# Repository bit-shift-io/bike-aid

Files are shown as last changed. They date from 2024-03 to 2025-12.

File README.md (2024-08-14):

# bike-aid

This is an ebike govenor which does the following:

* Bluetooth interface
* Power toggle
* Lights toggle
* Horn toggle
* Battery power, voltage, current meter
* Alarm system
* Speedometer
* Odometer
* Trip duration
* Throttle smoothing
* Throttle limiting / speed limiting
* Throttle deadband adjustment

## Purpose

I designed this tool as a controller to act as a interface for controlling my ebike. I have had a few ebikes now, and they are all missing basic features I wanted.

## Where to start

* mcu-nrf-rs - mcu software
* app-java - android app  
* docs - documentation
* diagrams - circuit diagrams
* everything else is old!

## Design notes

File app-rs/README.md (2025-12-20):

# Bike Aid (Rust + Flutter)

A high-performance, multiplatform Bluetooth application built with **Flutter** for the UI and **Rust** for the core logic.

> **Architecture Note**: This project uses **Rust** for all core application logic (UUIDs, parsing, state management) and **Dart/Flutter** strictly for the GUI and device transport. This separation allows for easily swapping the GUI framework in the future while preserving the business logic.

## Project Structure

### 🛠️ Core Logic (Rust)
The "brain" of the app lives in the `rust/` directory.
- **protocol.rs**: **Entry Point.** Contains the scooter protocol implementation.
  - `ScooterState`: The central data structure representing the bike (speed, battery, light status, etc.).
  - `parse_characteristic_data()`: Converts raw bytes from the bike into the `ScooterState`.
  - `create_command_bytes()`: Generates the raw bytes to send to the bike for actions like Power, Alarm, or Horn.
- **`src/api/`**: Contains the modules exposed to Flutter.

### 📱 Frontend (Flutter)
The UI and Bluetooth transport are in the `lib/` directory.
- **main.dart**: **GUI Entry Point.**
  - **Bluetooth Manager**: Handles scanning for "BScooter", auto-connecting, and characteristic subscriptions.
  - **Page Navigation**: Implements the fullscreen `PageView` (Dashboard <-> Log).
  - **Control Panel**: The button-based interface that triggers Rust commands.
- **`lib/src/rust/`**: **Generated Bridge.** Contains the Dart bindings that allow calling Rust functions seamlessly.

## Prerequisites

- **Flutter SDK**
- **Rust** (Stable)
- **Android NDK** (for Android builds)

## Setup & Running

### 1. Fix PATH & Install Tools (Once)
```fish
set -U fish_user_paths $HOME/.cargo/bin $fish_user_paths
cargo install flutter_rust_bridge_codegen --version 2.11.1
rustup target add aarch64-linux-android armv7-linux-androideabi x86_64-linux-android i686-linux-android
```

### 2. Generate Code
Run this to link the Rust code and generate translations:
```bash
flutter_rust_bridge_codegen generate
dart run slang
```

### 3. Run the App
```bash
flutter run
```

## Features
- **Native Bluetooth**: Fast and reliable scanning using `flutter_blue_plus`.
- **HTTP Entry Control**: Control IoT entry points via HTTP requests (with offline queuing).
- **Log & Diagnostic Terminal**: Real-time logging of Bluetooth commands and responses with manual UART input.
- **Permission Handling**: Dynamic requests for Location and Bluetooth.
- **Dark Theme**: Modern Material 3 dark UI.

## Troubleshooting

- **Missing Imports**: If `main.dart` shows errors after generation, uncomment the bridge imports at the top of the file.
- **Cargo Expand**: If generation fails with "cargo expand returned empty output", run `cargo build` inside the `rust/` folder once.

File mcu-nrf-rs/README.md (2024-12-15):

# Installation Guide

## Wiring
```
Raspberry pi debug probe (port D)   ->  NRF
TX/SC (orange - out from probe)     ->  CLK (orange - SWC) 
GND (black)                         ->  GND (black)
RX/SD (yellow - input to I/O)       ->  DIO (yellow - SWD)
```

## Tools
```Bash
# Probe-RS
curl --proto '=https' --tlsv1.2 -LsSf https://github.com/probe-rs/probe-rs/releases/latest/download/probe-rs-tools-installer.sh | sh

# USB Permissions
sudo usermod -aG uucp $USER # not sure if we need this one?

# need the udev rule
sudo cp 69-probe-rs.rules /etc/udev/rules.d/
sudo udevadm control --reload
sudo udevadm trigger

# Debugger - not required
#sudo pacman -S gdb-common openocd

# list debug probe
probe-rs list
```

## Getting rust working
Run ```cargo build``` in the rust project root directory  
Then ```cargo run```  
or ```cargo embed``` for user input terminal

## Error: No connected probes were found.
Need to configure udev rules in linux
```bash
probe-rs list
ls /dev/ttyACM*
lsusb
```

## Erase the chip
```bash
probe-rs erase --chip nRF52840_xxAA
```

## Get latest rust toolchain
```bash
rustup update
```

## Update nrf42840 firmware for bluetooth
Downloaded from 
```
https://www.nordicsemi.com/Products/Development-software/s140/download
```

Flash using the commands:
```bash
probe-rs erase --chip nrf52840_xxAA --allow-erase-all
probe-rs download --verify --binary-format hex --chip nRF52840_xxAA s140_nrf52_7.3.0_softdevice.hex
```

## Debug support
Install probe-rs visual studio plugin  
Download the svd ```https://github.com/nrf-rs/nrf-pacs/tree/master/svds```  
Old - Download the svd ```https://github.com/NordicSemiconductor/nrfx/blob/master/mdk/nrf52840.svd```  

## Reset device
Double tap rest to ground within 0.5 seconds to reset board

## Stuck in boot loop (bad flash)
Reflash the firmware above

## Pin Guide
* P0.31 - LED
* P0.29 - Piezo
* P0.20 - Manual Override
* P0.17 - Brake
* P0.09 - Speed
* P0.10 - Power Switch
* P0.10 - Light
* P1.11 - Horn
* P0.06 - I2C SCL - Orange ( Green on breadboard )
* P0.08 - I2C SDA - Yellow

## Pin Notes
* nfc-pins-as-gpio Allow using the NFC pins as regular GPIO P0_09/P0_10 on nRF52
* reset-pin-as-gpio Allow using the RST pin as a regular GPIO P0_18

* P0.13 controls vcc output on/off 3.3v
* P0.14-0.16 set low resets ?
* p0.15 Debug LED

## Hardware Todo
* try a smaller pulldown on the throttle module, replace 100k with 47k to see if it helps with floating throttle
* brake plug seems wobbly
* reset push button - hw
* speedo - hardware/oscilliscope
* brake supply 5v with diode to drop 0.7v. then can setup parkbrake to turn off power.

## App Todo
* disconnect while connecting causes multiple instances of scanner

## MCU Todo
* patch qeue predicate filter
* attach debugger to running mcu
* sport mode acceleration values 10% higher?
* alarm
* ble tracker
* odometer/speed

## Links

https://github.com/peterkrull/quad/blob/main/software/rusty-quad/src/

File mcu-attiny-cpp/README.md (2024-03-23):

# bike-aid
ebike throttle aid using arduino

### Purpose

Arduino Throttle Correction for 3-wire thottles

This project is suitable for electric vehicles with a non-programmable controller. 
The arduino is inserted between a 3-wire throttle and the controller.

* Provides smoothing for aggressive throttle response by slowing down changes in output (wheelie/jerk control)
* Reduces throttle dead-band/deadzone by mapping input to output values as per configuration
* Optionally provides an adjustable speed limit (hardcoded or potentiometer/switch)

### Wiring and Implementation

Wiring is very simple.  Smoothing capacitor can be any value that eliminates
jumping of motor speed at steady throttle.  I used a 10uF for my setup.  
A high value may cause the throttle to stay high longer than desired. 

### Tuning

Tune behaviors according to your throttle's actual values, which you can see if you watch serial output.

If you don't want speed limiting, comment out `#LIMIT_ENABLE`

**Note** that when plugged into USB, Arduino is running at 5V, but when powered by the motor controller,
it is most likely running on 4.0V-4.5V.  This changes the numbers and behavior a little when you unplug USB.

### Programming attiny85
https://www.instructables.com/How-to-Program-an-Attiny85-From-an-Arduino-Uno/
Files > Preferences > Additional Board Managers ...
https://raw.githubusercontent.com/damellis/attiny/ide-1.6.x-boards-manager/package_damellis_attiny_index.json
Restart the IDE
Tools > Boards > Board Manager
Install 'attiny'
Restart IDE
Tools > Boards > attiny

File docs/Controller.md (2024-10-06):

# EBike Controller

## Notes
Power switch take 48v, 16mA @ 55v

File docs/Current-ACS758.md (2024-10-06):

# ACS758LCB-050B Current Sensor
ACS758LCB-050B Range Linear Current Sensor Analog Signal Output for Arduino Hall Effect Based
Features and Benefits

## Notes

Maximum current: 100A
Voltage：3.3-5V
temperature：-41°C ~ 152°C
Industry-leading noise performance through proprietary amplifier and filter design techniques
Integrated shield greatly reduces capacitive coupling from current conductor to die due to high dV/dt signals, and prevents offset drift in high-side, high voltage applications
Total output error improvement through gain and offset trim over temperature
Small package size, with easy mounting capability
Monolithic Hall IC for high reliability
Ultra-low power loss: 100 μΩ internal conductor resistance
Galvanic isolation allows use in economical, high-side current sensing in high voltage systems
3.0 to 5.5 V, single supply operation
120 kHz typical bandwidth
3 μs output rise time in response to step input current
Output voltage proportional to AC or DC currents
Factory-trimmed for accuracy
Extremely stable output offset voltage
Nearly zero magnetic hysteresis

## Information

https://www.youtube.com/watch?v=SiHfjzcqnU4
http://robojax.com/learn/arduino/?vid=robojax-allegro_ACS758 - tutorial + source
http://robojax.com/download/datasheet/robojax_ACS758_current_sensor_datasheet.pdf

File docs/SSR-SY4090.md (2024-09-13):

# Solid State Relay SY4090

https://www.jaycar.co.nz/pcb-mount-solid-state-dil-relay/p/SY4090

## Notes

https://forum.arduino.cc/t/switch-55-60v-16ma-advice-optocouplers/1300792/10

## Calculations

V=IR
R=V/I
Forward Voltage LED = 1.2-1.3v
3.3v - 1.3v = 2v - 2.1v
R=2v/0.006A = 330ohm

## Pins
1 = +3.3v
2 = GND
3 = N/C
4/6 = Drain - Battery Input +60v 
5 = Source - Switched Output

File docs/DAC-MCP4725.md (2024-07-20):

# MCP4725 DAC

## Notes

MCP4725 Breakout Board 12-bit DAC I2C Interface
Use MCP4725 chip
12 DAC
Standard I2C interface
Power supply voltage 2.7-5.5V

## Information

https://www.aliexpress.com/item/1005005333707982.html?spm=a2g0o.order_list.order_list_main.90.66251802PaTEXk

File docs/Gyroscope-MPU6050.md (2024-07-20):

# MPU-6050 Gyroscope, Accelerometer, Temperature

## Information

https://randomnerdtutorials.com/arduino-mpu-6050-accelerometer-gyroscope/

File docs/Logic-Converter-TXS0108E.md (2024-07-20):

# TXS0108E Logic Converter

## Notes

Module uses the chip: TXS0108E
8-way high-speed full-duplex level conversion module
Provide two-way communication capability
VCCA terminal voltage of 1.2V-3.6V support
VCCB side support voltage 1.65v-5.5v
You can provide other common 3.3-5V 1.8-3.3v level conversion capability
The main application, 5V and 3.3V microcontroller module with 5V 3.3V microcontroller module, compatible with other communications support
MCU and SD card communication level conversion
SCM and iic, spi serial device level converter
OE active high enable IO recommended by a low voltage side of the IO port

## Information

https://www.aliexpress.com/item/1005006191464937.html?spm=a2g0o.order_list.order_list_main.56.66251802PaTEXk

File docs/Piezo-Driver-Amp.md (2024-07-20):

# Piezo Driver Amplifier

## Notes

Piezos make noise when you put an AC voltage across them: and the bigger the Vpp the louder they are. With your standard 3V logic microcontroller you can make 3Vpp with a PWM out, or 6Vpp differential with two complimentary outputs. But what if you want even louder? Or if you're using a piezo to sense distance using ultrasonic bounces?

We found the nifty PAM8904, which is an amplifier specifically designed for driving piezo elements - and unlike audio amplifiers it's good for up to 300 KHz! It's a switched-cap piezo driver that has bridge-tied load (BTL) output and up to 3x voltage multiplication thanks to a built in boosting circuit for up to ~13Vpp.

We whipped up a quick breakout in our 2mm JST-PH STEMMA form-factor to make it easy for anyone who wants to beep their boops very loudly. 

Usage is easy: power with 3 to 5VDC on the Vin and GND pins. Then provide a square wave on the signal pin, from 20Hz to 300KHz - any duty cycle is ok but 50% will probably work best. Theres a dual DIP switch to set the gain: you can set it to off (zero gain), x1 gain, x2 gain and x3 gain. The output is differential so 2x gain will give you 4xVin peak-to-peak across the piezo lines. Connect your piezo to the terminal block and you're ready to rock. 

Please note: If you are powering the driver from 5VDC, don't set the gain to x3 because the 15V output is higher than the driver is specified for. (Yeah we also sorta wondered why the chip manufacturer allows it). So if you are using 3.3V power, x3 gain is OK and will give you about 10V out but if you're powering with 5V use 2x gain max to keep the max voltage at 10V.

# Information

https://www.adafruit.com/product/5791
https://learn.adafruit.com/adafruit-stemma-piezo-driver-amp
https://learn.adafruit.com/adafruit-stemma-piezo-driver-amp/pinouts
https://dev.to/theembeddedrustacean/stm32f4-embedded-rust-at-the-hal-pwm-buzzer-3f1b

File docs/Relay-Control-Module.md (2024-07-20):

# Relay Control Module

## Notes

Specification:
Certification: NONE
Origin: Mainland China
Model Number: Relays Control Module
Main components: EL817, SRD-DC03V-SL-C
Voltage: DC 3V/3.3V
Can control 10A 250VAC, 10A 30VDC loads
Product weight: 20g
Product size: 70*20*17mm/2.76*0.79*0.67in
Note:
Due to the different monitor and light effect, the actual color of the item might be slightly different from the color showed on the pictures. Thank you!
Please allow 1-2cm measuring deviation due to manual measurement.
DC 3V/3.3V High Level Driver Module Output Signal Indicator High Level Trigger Microcontroller IO Port Optocoupler Relay Module
Features:
1. Output Signal Indicator: Equipped with an output signal indicator light, this dc 3v/3.3v high level driver module allows users to easily monitor and confirm the status of the signal output.
2. MCU-Compatible Input: With a signal input port that can be connected to MCU I/O pins, high level trigger provides a high-level signal drive and is compatible with various microcontrollers for easy integration into electronic projects.
3. Dual Power Supply Design: Featuring a dual power supply design, this product has strong anti-interference capabilities and reliable optical isolation protection, ensuring safe and stable signal transmission even in noisy environments.
4. Diode Continuity Protection: Equipped with diode continuity protection, optocoupler relay module can prevent any reverse current from dam aging the device and provide additional safety for your electronic projects.
5. Fast Response Time &amp; Long Relay Life: With a response time of less than 20 milliseconds and a relay life of up to 100,000 continuous operations, high level driver module delivers fast and reliable performance for various automation and control applications.
1 xIsolated Drive Control Board 

## Information

https://www.aliexpress.com/item/1005006178179016.html?spm=a2g0o.order_list.order_list_main.5.45b61802edvlUA

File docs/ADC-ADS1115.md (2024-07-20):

# ADC ADS1115

https://www.ti.com/product/ADS1115

## Notes

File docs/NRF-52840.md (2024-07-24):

# NRF 52840

https://wiki.icbbuy.com/doku.php?id=developmentboard:nrf52840

https://github.com/joric/nrfmicro/wiki/Alternatives#supermini-nrf52840

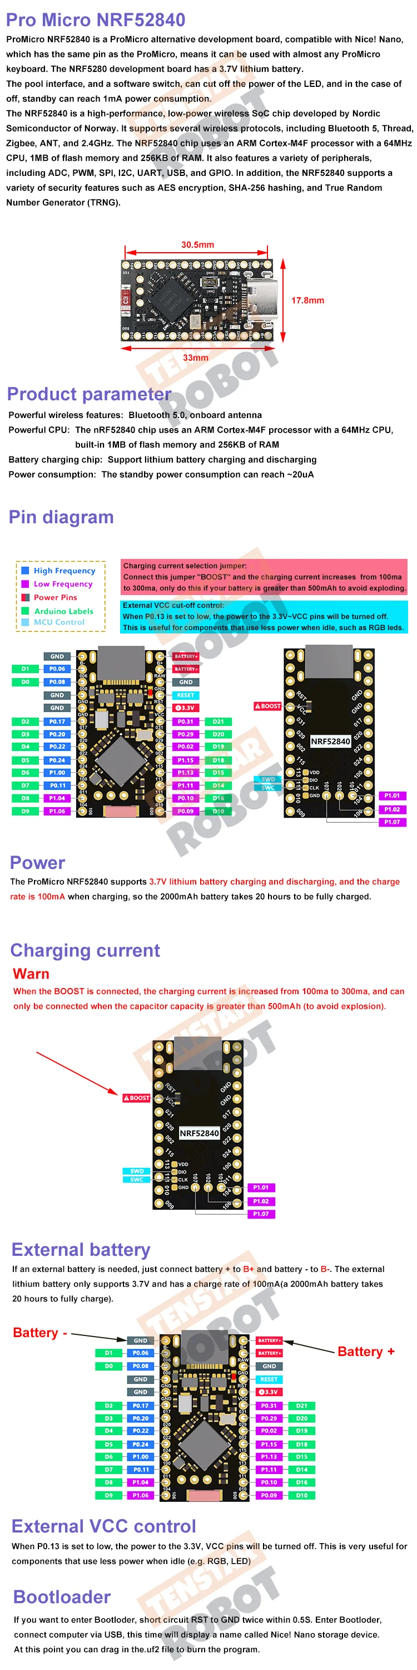
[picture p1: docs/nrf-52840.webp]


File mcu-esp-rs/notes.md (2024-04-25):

https://github.com/esp-rs/esp-hal/tree/main/examples
https://github.com/peterkrull/quad/blob/main/software/rusty-quad/src/task_blinker.rs
https://github.com/embassy-rs/embassy/blob/main/examples/nrf52840/src/bin/channel_sender_receiver.rs
https://github.com/apollolabsdev/ESP32C3/blob/main/embassy_examples/gpio/src/main.rs
https://dev.to/apollolabsbin/sharing-data-among-tasks-in-rust-embassy-synchronization-primitives-59hk
https://hegdenu.net/posts/understanding-async-await-3/

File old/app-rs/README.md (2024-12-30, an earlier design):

# Bike-Aid-App

A Rust application that's using [Slint](https://slint.rs) for the user interface. Using bluetooth low energy (BLE) and desktop and mobile app.

## VSCode plugins
Slint  
rust-analyzer  
CodeLLDB  

## Setup Android
Install sdk & ndk in the ~/Android/ directory  

Install dependencies  
```bash
sudo pacman -S jdk17-openjdk 
# clang lld llvm - use android ndk tools instead
```

Install android tools
```bash
sudo pacman -S android-tools android-udev
```

Set env variables in ~/.bash_profile 
```bash
export ANDROID_HOME=$HOME/Android/Sdk
export ANDROID_NDK_HOME=$ANDROID_HOME/ndk/28.0.12674087/
export ANDROID_NDK_ROOT=$ANDROID_NDK_HOME
export PATH=$PATH:$ANDROID_NDK_HOME/toolchains/llvm/prebuilt/linux-x86_64/bin

# for skia bindings
export ANDROID_NDK=$ANDROID_NDK_HOME
export CC_aarch64_linux_android=aarch64-linux-android26-clang
export CXX_aarch64_linux_android=aarch64-linux-android26-clang++
export AR_aarch64_linux_android=llvm-ar
export CARGO_TARGET_AARCH64_LINUX_ANDROID_LINKER=aarch64-linux-android26-clang
```

Install rust tools
```bash
rustup update
rustup target add aarch64-linux-android
cargo install cargo-ndk
```

Run and test
```sudo adb devices```

## Android Gradle Build
``` bash
cargo ndk -t arm64-v8a -o android/app/src/main/jniLibs/  build --features=android
cd android
./gradlew build
./gradlew installDebug
```

working as an apk... need libs?
```bash
cargo apk run --target aarch64-linux-android --lib
```

## Android xbuild -old?
```bash
x doctor
x devices
x build
x build --device adb:<id>
x run --device adb:<id>
```

## Android cargo-apk - untested
```bash
rustup target add aarch64-linux-android
cargo install cargo-apk
cargo apk build
cargo apk run
```

## Build external packages
```
<cd to Projects folder>
git clone https://github.com/deviceplug/jni-utils-rs.git
cd jni-utils-rs
cargo build --features=build-java-support
jar files located in /target/debug/java/libs

cd ..
git clone https://github.com/deviceplug/btleplug.git
cd btleplug/src/droidplug/java
edit build.gradle, comment and replace:
dependencies {
    implementation files('/home/bronson/Projects/jni-utils-rs/target/debug/java/libs/jni-utils-0.1.1-SNAPSHOT.jar')
}
./gradlew build 
btleplug/src/droidplug/java/build/outputs/aar/
```
an optional idea could be to merge the 2 android folders and build?

## Getting rust working
Run ```cargo build``` in the rust project root directory  
Then ```cargo run```

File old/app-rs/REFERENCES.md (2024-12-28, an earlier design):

## Links

#### BLE

https://github.com/MnlPhlp/blec

#### Android
https://github.com/slint-ui/slint/tree/3aafce2c52fa1e14971e4f2455bdc556daeb079d/internal/backends/android-activity

https://github.com/slint-ui/slint/blob/master/examples/todo/rust/lib.rs

https://git.sr.ht/~tmpod/eigen/tree/main/item/src

https://github.com/search?q=repo%3Aslint-ui%2Fslint%20android&type=code

https://crates.io/crates/android-activity

https://docs.rs/android-manifest/latest/android_manifest/struct.UsesPermission.html

#### JNI

https://docs.rs/jni/latest/jni/

https://github.com/astonbitecode/j4rs

#### Build.rs

https://github.com/slint-ui/slint/blob/e0f3fd4168fa6ad5ed17a50910111ed72d1ae95e/internal/backends/android-activity/build.rs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

# btleplug

https://github.com/deviceplug/btleplug/tree/master
https://github.com/deviceplug/btleplug/issues/8
https://gist.github.com/qdot/210f31439888927fc23b14d2e3d40503

# other apps

https://github.com/MiniMinerX/bevy_gaussian_oxr_simple/blob/main/manifest.yaml

https://gitlab.com/loikki/open-biking/-/tree/main?ref_type=heads
https://github.com/kyrosle/bevy_android
https://github.com/rust-mobile/xbuild
https://github.com/slint-ui/slint/blob/e125da180d34df9e221cb925ea5c1af6e813bd8f/api/rs/slint/android.rs
https://github.com/trobanga/flutter_btleplug/tree/frb2
https://github.com/intiface/intiface-central/tree/main
https://github.com/rib/bluey

# crate apis
https://github.com/rust-mobile/android-activity
https://github.com/rust-mobile/ndk

# idea

1. get access to the class loader from android-activity(slint is using this).
2. load the classes using this method.
see here: 

https://github.com/rust-mobile/android-activity/issues/82

https://github.com/rib/bluey/blob/5f351c50e6f396bc4fef9c050599f9668c63b339/bluey/src/android/session.rs#L1017

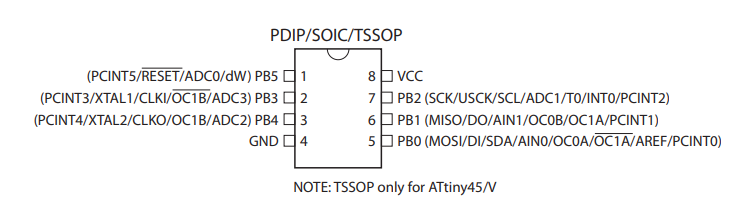
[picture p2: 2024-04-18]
mcu-attiny-cpp/pintout.png

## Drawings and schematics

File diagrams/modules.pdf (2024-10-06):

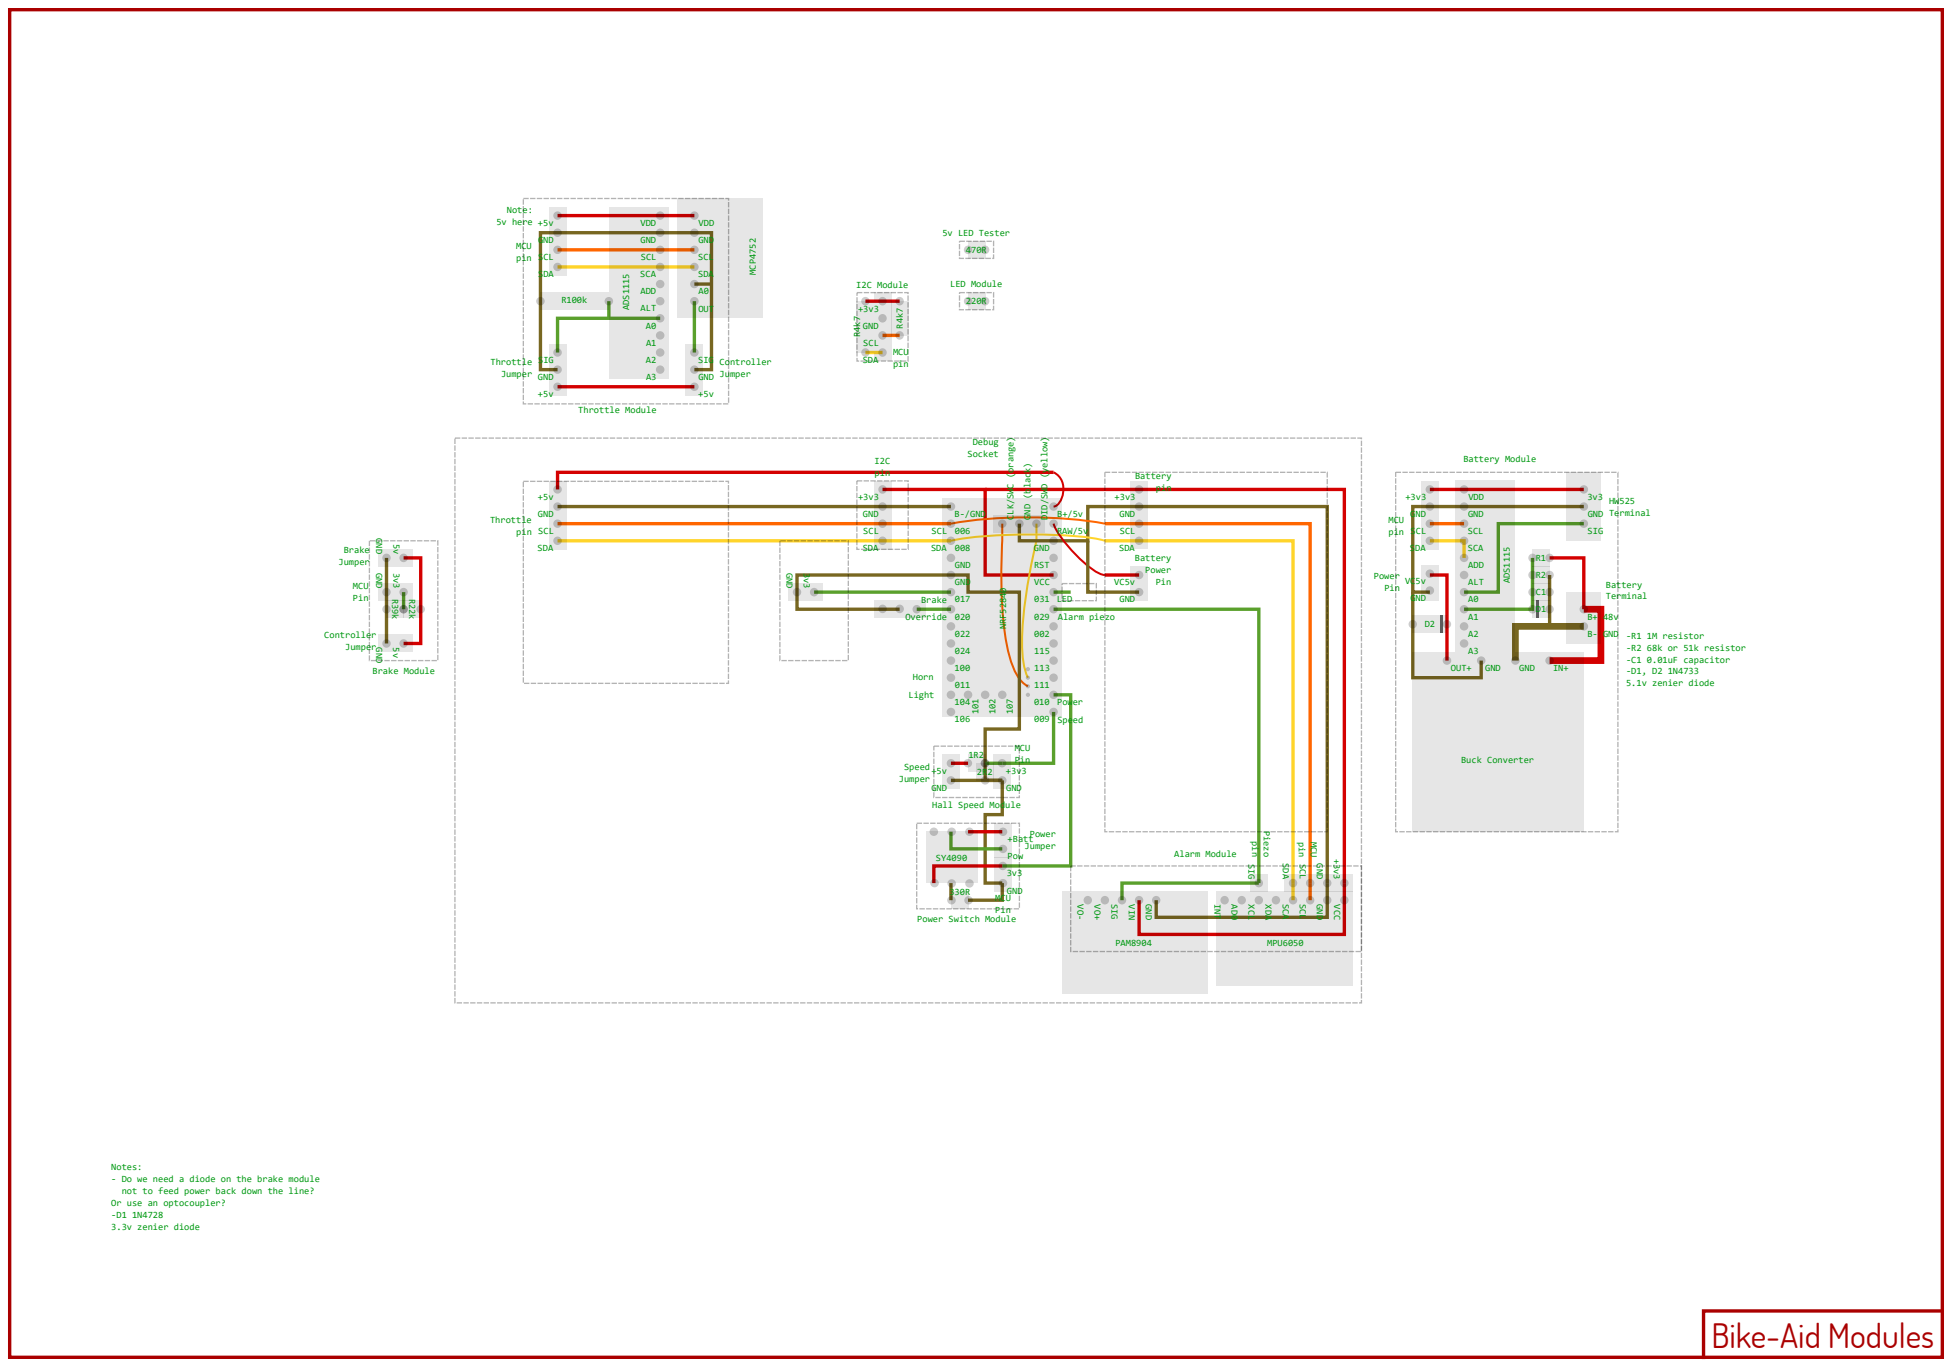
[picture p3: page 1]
B-/GND; GND; RAW/5v; RST; VCC; NRF52840; SCL; Debug Socket; Light; Power; Horn; Brake; Override; Alarm piezo; LED; Speed; SDA; GND (black); I2C pin; Battery pin; Battery Power Pin; Throttle pin; OUT+; Buck Converter; VDD; SCA; ADD; ALT; ADS1115; MCU pin; Power Pin; SIG; HW525 Terminal; B- GND; Battery Terminal; Battery Module; -R1 1M resistor -R2 68k or 51k resistor -C1 0.01uF capacitor -D1, D2 1N4733 5.1v zenier diode; OUT; MCP4752; Note: 5v here; Throttle Jumper; Controller Jumper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

CLK/SWC (orange)

DID/SWD (yellow)

Power Switch Module

Notes:
- Do we need a diode on the brake module
not to feed power back down the line?
Or use an optocoupler?
3.3v zenier diode

Bike-Aid Modules

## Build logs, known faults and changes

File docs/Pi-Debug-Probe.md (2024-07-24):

# Raspberry Pi Debug Probe

https://www.raspberrypi.com/documentation/microcontrollers/debug-probe.html

## Notes

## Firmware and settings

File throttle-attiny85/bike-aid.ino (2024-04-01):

/**
 * Based on Akom's smooth throttle using an Arduino
 * https://github.com/akomakom/arduino-throttle-smoother
 * 
 * Smoothing throttle response - adjustable by potentiometer
 * Minimize deadband/deadzone
 * Speed limit - adjustable by potentiometer
 */

/* 
PINS
===========================
*/
#ifdef ARDUINO_AVR_NANO
const byte THROTTLE_SMOOTHING_PIN_IN = A1;
const byte THROTTLE_PIN_LIMIT_IN = A2;

const byte THROTTLE_SIGNAL_PIN_IN = A0;
const byte THROTTLE_SIGNAL_PIN_OUT = 10; // 10 = D10

#else // ATTINY
const byte PIN_01 = PB5; // p1
const byte THROTTLE_SMOOTHING_PIN_IN = PB3; // p2
const byte THROTTLE_PIN_LIMIT_IN = PB4; // p3 ok

const byte THROTTLE_SIGNAL_PIN_IN = PB2; // p7
const byte THROTTLE_SIGNAL_PIN_OUT = PB1; // p6
#endif


/* 
Deadband / Deadzone
===========================
Adjust throttle range to eliminate deadband/deadzones

MAP_IN - Normal range of throttle
MAP_OUT - range to output to controller

All the ranges below can be determined by watching the serial console and twisting the throttle, they will be slightly wrong if the controller supplies less than 5v USB to throttle.
Preferably, use a multimeter to measure voltage output from the throttle on your ebike and use the formula like so to calculate the numbers:
( Signal Voltage / Supply Voltage ) * 1023

THROTTLE_MAP_IN_MIN - Voltage when the throttle is unpressed
THROTTLE_MAP_IN_MAX - Voltage when the throttle is fully pressed
THROTTLE_MAP_OUT_MIN - Voltage just before the motor starts to activate the wheels
THROTTLE_MAP_OUT_MAX - Voltage just after max speed (or use supply voltage otherwise)

Then verify the output with a multimeter also to tweak the ranges THROTTLE_MAP_OUT_MIN, and THROTTLE_MAP_OUT_MAX
*/
// supply voltage - 4.36v
const int THROTTLE_MAP_IN_MIN = 199; // 0.847v no throttle
const int THROTTLE_MAP_IN_MAX = 840; // 3.58v full throttle
const int THROTTLE_MAP_OUT_MIN = 288; // 1.23v just before motor active
const int THROTTLE_MAP_OUT_MAX = 1023; //620 // 2.6v just after max speed

/* 
Speed Limit
===========================
adjusts throttle output speed limit
*/
#define THROTLE_LIMIT_ENABLE // comment to disable speed limit feature
// pot input is 0-1023, map this to output range
const int THROTTLE_LIMIT_MAP_OUT_MIN = 100;
const int THROTTLE_LIMIT_MAP_OUT_MAX = 1023;

/* 
Smoothing - Jerkiness Mitigation
===========================
how quickly to adjust output, larger values are slower
smoothing over time
*/
// pot input is 0-1023, map this to output range
const int THROTTLE_SMOOTH_MAP_OUT_MIN = 1; // never zero to avoid divide by zero
const int THROTTLE_SMOOTH_MAP_OUT_MAX = 2000;
const int THROTTLE_DECREASE_SMOOTH_FACTOR = 100;
//const int THROTTLE_INCREASE_SMOOTH_FACTOR = 4000; // potentiometer now

// Delay between loops in ms
const int THROTTLE_INTERVAL = 1;
const int DEBUG_PRINT_INTERVAL = 250;

// global variables
float throttle_output = 0; // 0-1023, later throttle_mapped_output to 0-255
unsigned long last_throttle_interval = 0;
unsigned long last_debug_print_interval = 0;


void setup() {
  //analogReference(EXTERNAL);

  #ifdef ARDUINO_AVR_NANO
  Serial.begin(9600);
  #endif

  pinMode(PIN_01, INPUT); // p1 above ground test
  pinMode(THROTTLE_SMOOTHING_PIN_IN, INPUT);
  pinMode(THROTTLE_PIN_LIMIT_IN, INPUT);
  pinMode(THROTTLE_SIGNAL_PIN_IN, INPUT);
  pinMode(THROTTLE_SIGNAL_PIN_OUT, OUTPUT); // output

  //throttle_output = analogRead(THROTTLE_SIGNAL_PIN_IN); // initial value

  /*
  // safety feature for disconnected throttle
  // ensure throttle is not in use
  while(analogRead(THROTTLE_SIGNAL_PIN_IN) > 400) // todo: use THROTTLE_MAP_OUT_MIN
  {
    #ifdef ARDUINO_AVR_NANO
    Serial.println("Error: Throttle wire has no signal!");
    Serial.println(analogRead(THROTTLE_SIGNAL_PIN_IN));
    #endif
  }
  */

  // wait for sensors to stabalise
  delay(100);
}

void loop() {
    int in = analogRead(PIN_01);
    analogWrite(THROTTLE_SIGNAL_PIN_OUT, in / 4); // debug - ok
    //analogWrite(THROTTLE_SMOOTHING_PIN_IN, 192); // debug
    //analogWrite(THROTTLE_PIN_LIMIT_IN, 64); // debug - ok
    //analogWrite(THROTTLE_SIGNAL_PIN_IN, 64); // debug
  //throttle();
}


void throttle() {
  unsigned long time = millis();

  if ((last_throttle_interval + THROTTLE_INTERVAL) < time) {
    last_throttle_interval = time;

    // throttle hall sensor input
    int throttle_input = analogRead(THROTTLE_SIGNAL_PIN_IN);
    // delta computed smoothing/error from last setting (throttle_output)
    int throttle_delta = throttle_input - throttle_output; // smoothing/error

    // smoothing potentiometer
    int throttle_smooth_input = analogRead(THROTTLE_SMOOTHING_PIN_IN);
    int throttle_smooth_mapped = map(throttle_smooth_input, 0, 1023, THROTTLE_SMOOTH_MAP_OUT_MIN, THROTTLE_SMOOTH_MAP_OUT_MAX); // THROTTLE_INCREASE_SMOOTH_FACTOR

    // how much to change (+/-) throttle value this itr
    float throttle_adjustment = (float) throttle_delta / (float) (throttle_delta > 0 ? throttle_smooth_mapped : THROTTLE_DECREASE_SMOOTH_FACTOR);

    #ifdef THROTLE_LIMIT_ENABLE
    // limit potentiometer
    int throttle_limit_input = analogRead(THROTTLE_PIN_LIMIT_IN);
    // Apply speed limit - allow increase only if below limit
    if (throttle_output > map(throttle_limit_input, 0, 1023, THROTTLE_LIMIT_MAP_OUT_MIN, THROTTLE_LIMIT_MAP_OUT_MAX)) {
      throttle_adjustment = min(throttle_adjustment, 0); // always allow decrease
    }
    #endif

    throttle_output += throttle_adjustment;

    // throttle to output value map - mapping to controller range
    int throttle_mapped_output = map(throttle_output, THROTTLE_MAP_IN_MIN, THROTTLE_MAP_IN_MAX, THROTTLE_MAP_OUT_MIN, THROTTLE_MAP_OUT_MAX);

    // PWM is 0-254 while our values are 0-1023
    analogWrite(THROTTLE_SIGNAL_PIN_OUT, throttle_mapped_output / 4);

    #ifdef ARDUINO_AVR_NANO
    if ((last_debug_print_interval + DEBUG_PRINT_INTERVAL) < time) {
      last_debug_print_interval = time;
      // format for serial plotter
      //Serial.print(",Th_In:");Serial.print(throttle_input);
      //Serial.print(",Th_Out:");Serial.print(throttle_output);
      Serial.print(",Th_Map:");Serial.print(throttle_mapped_output);
      //Serial.print(",Th_Adj:");Serial.print(throttle_adjustment);
      Serial.print(",Lim_In:");Serial.print(throttle_limit_input);
      Serial.print(",Smo_In:");Serial.print(throttle_smooth_input);
      Serial.print(",G1:");Serial.print(THROTTLE_MAP_OUT_MIN); // guide
      Serial.print(",G2:");Serial.print(THROTTLE_MAP_OUT_MAX); // guide
      Serial.println();
    }
    #endif

  }
}

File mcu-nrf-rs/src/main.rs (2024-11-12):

#![no_std]
#![no_main]

// modules/creates
mod tasks;
mod examples;
mod ble;
mod utils;

use tasks::*;
use utils::{i2c, signals};

use defmt::info;
use embassy_nrf::config::Config;
use embassy_nrf::{config::Reg0Voltage, gpio::Pin};
use embassy_time::Timer;
use embassy_nrf::interrupt::Priority;
use embassy_executor::Spawner;


#[embassy_executor::main]
async fn main(spawner: Spawner) {

    // == INIT ==

    rtt::init(spawner);
    info!("======== Starting ========");
    let p = embassy_nrf::init(get_config()); // make mut if need be for shared resources
    Timer::after_secs(2).await; // sleep incase we need to flash during debug and get a crash
    //let (spawn_high, spawn_med) = init_priority_spawners();
   
    // == I2C DEVICES ==

    let i2c_bus = i2c::init(p.TWISPI0, p.P0_08.degrade(), p.P0_06.degrade());

    spawner.must_spawn(throttle_adc::task(i2c_bus));
    spawner.must_spawn(throttle_dac::task(i2c_bus));
    spawner.must_spawn(gyroscope::task(i2c_bus));
    spawner.must_spawn(temperature::task(i2c_bus));
    spawner.must_spawn(battery_adc::task(i2c_bus));
 
    // == TASKS ==

    spawner.must_spawn(switch_power::task(p.P0_10.degrade()));
    spawner.must_spawn(cli::task());
    spawner.must_spawn(brake::task(p.P0_17.degrade()));
    spawner.must_spawn(park_brake::task());
    spawner.must_spawn(speed::task(p.P0_09.degrade()));
    spawner.must_spawn(power_down::task());
    spawner.must_spawn(manual_override::task(p.P0_20.degrade()));
    spawner.must_spawn(battery::task());
    spawner.must_spawn(piezo::task(p.PWM0, p.P0_29.degrade())); // disable when debug to mute
    spawner.must_spawn(alarm::task());
    spawner.must_spawn(throttle::task());
    spawner.must_spawn(cruise::task());
    spawner.must_spawn(bluetooth::task(spawner));
    spawner.must_spawn(led::task(p.P0_31.degrade(), 0));
    spawner.must_spawn(led::task(p.P0_15.degrade(), 1));
    spawner.must_spawn(clock::task());

    // == FINALISE ==

    boot_ok().await;
    debug(spawner).await;
}


// #[allow(dead_code)]
// fn init_priority_spawners() -> (SendSpawner, SendSpawner) {
//     static EXECUTOR_HIGH: InterruptExecutor = InterruptExecutor::new();
//     static EXECUTOR_MED: InterruptExecutor = InterruptExecutor::new();

//     #[interrupt]
//     unsafe fn SWI1_EGU1() {
//         EXECUTOR_HIGH.on_interrupt()
//     }

//     #[interrupt]
//     unsafe fn SWI0_EGU0() {
//         EXECUTOR_MED.on_interrupt()
//     }

//     // High-priority executor: SWI1_EGU1, priority level 6
//     interrupt::SWI1_EGU1.set_priority(Priority::P6);
//     let spawner_high = EXECUTOR_HIGH.start(interrupt::SWI1_EGU1);

//     // Medium-priority executor: SWI0_EGU0, priority level 7
//     interrupt::SWI0_EGU0.set_priority(Priority::P7);
//     let spawner_med = EXECUTOR_MED.start(interrupt::SWI0_EGU0);

//     (spawner_high, spawner_med)
// }


fn get_config() -> Config {
    let mut c = Config::default();
    // change interrupts for softdevice - levels 0, 1 and 4 are reserved by the softdevice
    c.gpiote_interrupt_priority = Priority::P2;
    c.time_interrupt_priority = Priority::P2;
    // voltage from 2.8v to 3.3v
    c.dcdc.reg0 = true;
    c.dcdc.reg0_voltage = Some(Reg0Voltage::_3v3);
    c
}


async fn boot_ok() {
    Timer::after_millis(10).await;
    info!("======== Boot Ok ========");
    let send_led = signals::LED_MODE.sender();
    let send_piezo = signals::PIEZO_MODE.sender();
    send_led.send(signals::LedModeType::SingleSlow);
    send_piezo.send(signals::PiezoModeType::Boot);
}


async fn debug(_spawner: Spawner) {
    // Timer::after_millis(10).await;
    // info!("======== Debug ========");

    // use examples::signal_test;
    // spawner.must_spawn(signal_test::task(spawner));
    
    // use crate::examples::i2c_scan;
    // spawner.must_spawn(i2c_scan::task(i2c_bus));

    // turn device on for testing
    //Timer::after_millis(100).await;
    //let send_power = signals::POWER_ON.sender();
    //send_power.send(true);
}

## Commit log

2024-03-19 uart gui wip
2024-03-19 uart gui clean
2024-03-27 kidcad schematic
    [schematic.kicad_sch]
2024-03-28 add filter resistor
    [schematic.kicad_sch]
2024-04-01 convert to classes
    [schematic.kicad_sch]
2024-04-09 esp32 fixes
2024-04-10 rename module
    [schematic.kicad_sch]
2024-04-13 low power mode
2024-04-19 ble uart
2024-06-26 led test
2024-06-29 i2c dac test
2024-06-29 temperature from chip
2024-06-30 throttle port
2024-07-04 shared i2c/twi bus working
2024-07-04 tidy throttle
2024-07-06 test interrupt
2024-07-07 git support, voltage to 3.3v
2024-07-07 saadc works at 3.3v
2024-07-07 calibration dac adc
2024-07-08 gyro and alarm
2024-07-09 priority fixed for softdevice
    [schematic.kicad_sch]
2024-07-10 gyroscope motion and temperature
2024-07-11 new alarm with gyro
2024-07-12 power working over ble
2024-07-18 ble uart tidy
2024-07-20 docs & diagrams
    [throttle_module.kicad_sch, voltage_dividers.kicad_sch]
2024-07-21 throttle speed limit wip
2024-07-22 tidy up files & throttle
2024-07-22 uart work
2024-07-23 uart works correctly
2024-07-28 new android app
    [schematic.kicad_sch]
2024-08-01 smoothing throttle
2024-08-06 svg diagrams
    [modules.kicad_sch]
2024-08-10 buttons working
2024-08-12 settings over uart
2024-08-12 testing power states in clock
2024-08-13 power working in clock and led
2024-08-14 power state works
2024-08-15 app buttons work
2024-08-15 fix led task
2024-08-31 battery module
2024-09-03 battery level ble
2024-09-05 main board layout
2024-09-13 new power module
2024-09-27 initial firmware for working device
2024-09-28 panic reset and cli tweaks
    [main.rs]
2024-09-30 park brake
2024-10-02 park brake safety
2024-10-04 refactor throttle
2024-10-05 throttle optimisations
2024-10-06 extra park brake
2024-10-07 cruise fix & alarm
    [main.rs]
2024-10-08 replace spawners with async join
    [main.rs]
2024-10-10 seperate park brake and power down tasks
2024-10-13 refactor watch brake & park
2024-10-14 power down & tidy
2024-10-15 more watch, ble data cruise, brake, park
2024-10-16 replaced all pubsub with watch
    [main.rs]
2024-10-17 experimental command que added
2024-10-18 experimental command que work
2024-10-21 command que working & app fixes
    [main.rs]
2024-10-22 fix power cycle bugs
    [main.rs]
2024-10-30 dataslice for uart and fixes
2024-10-30 panic persist and uart fixes
    [main.rs]
2024-11-03 added throttle level to app
2024-11-05 convert i2c to async with async drivers
2024-11-06 fix power on bugs and i2c crashes
    [main.rs]
2024-11-06 async drivers tested and fixed
    [main.rs]
2024-11-07 profile and optimised throttle adc
2024-11-08 ble send no longer async
    [main.rs]
2024-11-08 cli, cruise & throttle changes
2024-11-09 throttle tidy up
2024-11-09 i2c device available before use
2024-11-10 cleanup power asyncs
2024-11-12 replaced chains in park brake with experimental neater code
    [main.rs]
2024-11-13 replaced chains with select
    [main.rs]
2024-11-13 i2c unsafe pointer to mut ref
2024-12-14 brake tap for cruise
2024-12-14 battery idle mode report
2026-01-04 entry button
